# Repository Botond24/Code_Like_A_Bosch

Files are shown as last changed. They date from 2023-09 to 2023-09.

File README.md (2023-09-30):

# Code Like A Bosch Challenge
## Hardware Chalenge
### Ideas
- lapma
- toldo
- nyomatek kijelzo
- Nekem az ötletem a szogmérő, ezt 2 dologra is használhatjuk
    - Egyrészt segíthet kezdőknek hogy jól tartsák a fúrót
    - Másrészt vízszint mérő

### TODO -- Moved to Obsidian/Main doc.md

1. Brainstorm and decide on an idea that can enhance the Bosch 12 screwdriver
    - Business model of your solution
    - Customer need for your extension – how many new customers could be acquired with the new extension
    - Value added for the customer – comfort, safety, efficiency, versatility
    - Feasibility – is this can be really realized?
    - Costs – development, BOM, sale price
2. Overview of the proposed solution – block diagram, infographics, etc.
3. Schematic of the proposed solution – the real connection between the components, modules, can be done in CAD, or in paint.
4. Simulations and calculations of the main component, or part of the hardware (if applicable)
5. Documentation of your idea and solution
6. Firmware block diagram (only if applicable to your idea)
7. Firmware code, or segment of your algorithm (only if applicable to your idea)
8. Explain your idea and introduce your team in a video
9. Optional for additional points: start prototyping and bring your idea to life with the provided tools, hardware components on site (HW + firmware)

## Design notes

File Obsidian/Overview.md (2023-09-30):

```mermaid
graph TD
    phase1["`phase 1
    figuring out what can help people`"] --> phase2["`phase 2
    search for a way to make it low cost`"] --> phase3["`phase 3
    desing the screwdriver inside to make everthing fit`"] --> phase4["`phase 4
    build a prototype and test is it useable`"] --> phase5["`phase 5
    finishing touches to the production version`"]
```

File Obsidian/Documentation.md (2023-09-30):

# Documentation

## System Block Diagram
```mermaid
graph TD
	MCU --> Display
	TOF[Proximity Sensor x4] --> MCU
	12V --> DCDC
	DCDC --> MCU
	DCDC --> TOF
```

## BOM

| Item | Qty | Reference(s) | Value | LibPart | Footprint | Datasheet | DNP | Height | Manufacturer_Name  | Manufacturer_Part_Number | Mouser Part Number | Mouser Price/Stock |
|:-----|:----|:---|:---|:---|:---|:---|:----|:---|:---|:---|:---|:---|
| 2 | 5 | C5, C6, C7, C8, C14 | GRT155R61A475ME13J | GRT155R61A475ME13J:GRT155R61A475ME13J | CAPC1005X55N | https://psearch.en.murata.com/capacitor/product/GRT155R61A475ME13%23.html | | 0.55 | Murata Electronics | GRT155R61A475ME13J | 81-GRT155R61A475ME3J | https://www.mouser.co.uk/ProductDetail/Murata-Electronics/GRT155R61A475ME13J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 |
| 3 | 1 | C11 | C0402C271K5RAC | C0402C271K5RAC:C0402C271K5RAC | CAPC1005X55N | https://content.kemet.com/datasheets/KEM_C1002_X7R_SMD.pdf | | 0.55 | KEMET | C0402C271K5RAC | 80-C0402C271K5RAC | https://www.mouser.co.uk/ProductDetail/KEMET/C0402C271K5RAC?qs=cr8T4Ugre45g%252BE5NGMDJuA%3D%3D |
| 4 | 1 | C12 | GRM188R61C106MA73J | GRM188R61C106MA73J:GRM188R61C106MA73J | CAPC1608X90N | http://componentsearchengine.com/Datasheets/1/GRM188R61C106MA73J.pdf | | 0.9 | Murata Electronics | GRM188R61C106MA73J | 81-GRM188R61C106MA3J | https://www.mouser.co.uk/ProductDetail/Murata-Electronics/GRM188R61C106MA73J?qs=QzBtWTOodeVxskQb7yWr5w%3D%3D |
| 5 | 1 | J1 | Conn_01x04_Pin | Connector:Conn_01x04_Pin | Connector_PinSocket_1.00mm:PinSocket_1x04_P1.00mm_Vertical | ~ | | | | | | |
| 6 | 1 | L1 | SRN2012T-6R8K | SRN2012T-6R8K:SRN2012T-6R8K | INDPM2012X120N | http://www.bourns.com/docs/Product-Datasheets/SRN2012T.pdf | | 1.2 | Bourns | SRN2012T-6R8K | 652-SRN2012T-6R8K | https://www.mouser.co.uk/ProductDetail/Bourns/SRN2012T-6R8K?qs=A6eO%252BMLsxmSuOZAvAVKYXQ%3D%3D |
| 7 | 1 | R1 | 0603WAJ0103T5E | 0603WAJ0103T5E:0603WAJ0103T5E | RESC1608X55N | | | 0.55 | ROYALOHM | 0603WAJ0103T5E | 303-0603WAJ0103T5E | https://www.mouser.co.uk/ProductDetail/Royalohm/0603WAJ0103T5E?qs=e8oIoAS2J1RbD%2Fl9RKhEzg%3D%3D |
| 8 | 1 | U1 | STM32C011J_4-6_Mx  | MCU_ST_STM32C0:STM32C011J_4-6_Mx | Package_SO:SOIC-8_3.9x4.9mm_P1.27mm | https://www.st.com/resource/en/datasheet/stm32c011j4.pdf | | | | | | https://eu.mouser.com/ProductDetail/STMicroelectronics/STM32C011J4M6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|
| 9 | 1 | U2 | ~ | Converter_DCDC:IEB0112S3V3 | Converter_DCDC:IEB01 | | | | | | | |
| 10 | 1 | U3 | ~ | Driver_Display:SSD1306 | Connector_PinSocket_1.00mm:PinSocket_1x04_P1.00mm_Vertical | | | | | | | |
| 11 | 4 | U4, U5, U6, U7 | VL53L0CXV0DH_1 | VL53L0CXV0DH_1:VL53L0CXV0DH_1 | KiCad:LGA12_1 | http://www.st.com/content/ccc/resource/technical/document/datasheet/group3/b2/1e/33/77/c6/92/47/6b/DM00279086/files/DM00279086.pdf/jcr:content/translations/en.DM0027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 | | | STMicroelectronics | VL53L0CXV0DH/1 | 511-VL53L0CXV0DH/1 | https://www.mouser.co.uk/ProductDetail/STMicroelectronics/VL53L0CXV0DH-1?qs=dTJS0cRn7ojtsK3C9%252BTaSw%3D%3D |  

4x2.32 + 1x0.493 + 1x0.001 + 1x0.068 + 1x0.034 + 1x0.05 + 5x0.02 + 1x64.10 + development = 74.126  + development = 89.99 EUR
## Schematic

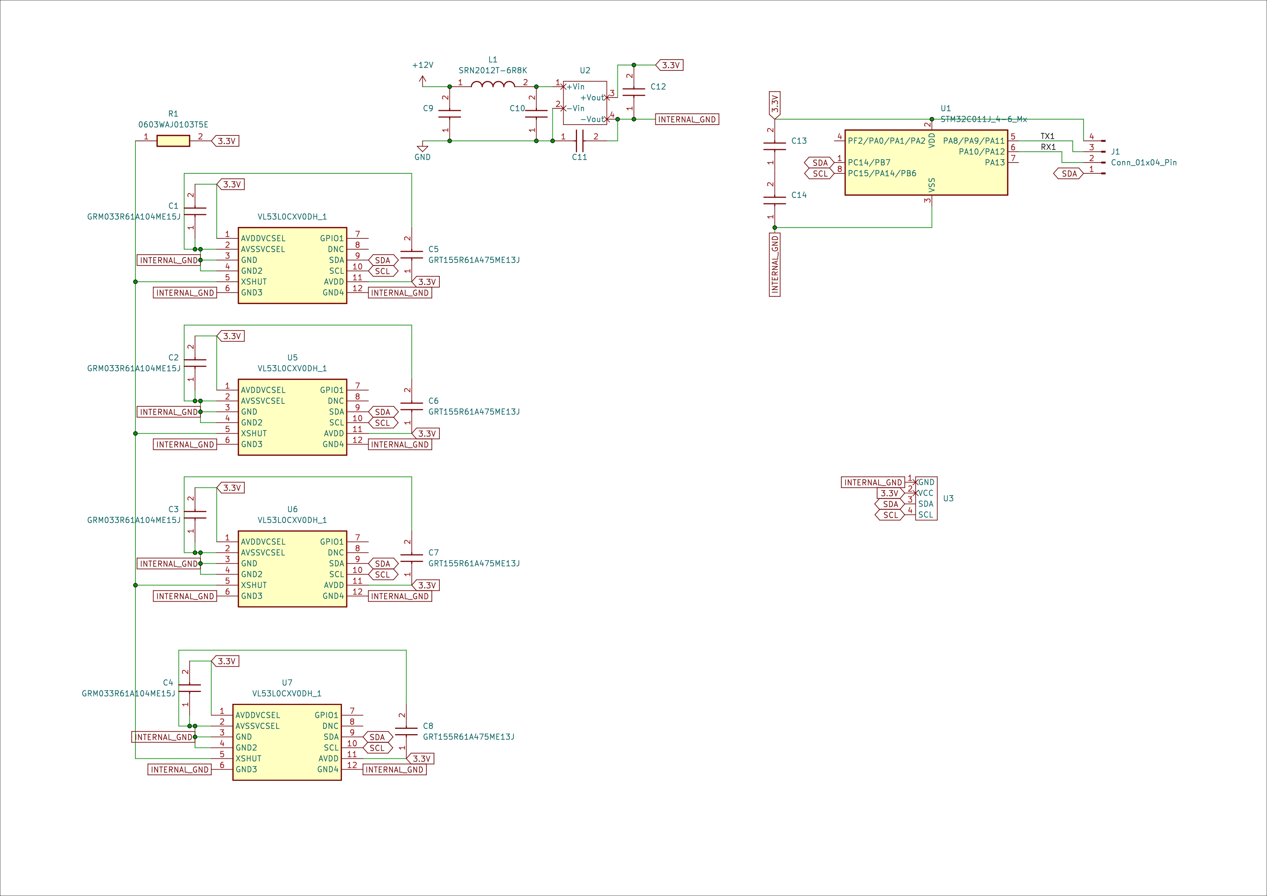
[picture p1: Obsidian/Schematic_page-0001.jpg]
Schematic


## Calculations

We calculated the distance of the head fron the screw, and the angle using only 2 of the sensors.
</br></br>
The formulas we came up with:
$$d_0 = \frac{D_{s1} +d_{s2}}{2}, \alpha = \tan\left(|{d_{s1}-d_s2}|\right)$$

These of course work with any of the opposing sensors to get the anglo of the given axis.

## Working Priciple

With the TOF sensors we get the distance difference, and use that to calculate the angle in the given axis.

The TOF has a range from 5cm to 120cm being more than enough for our purposes.

## Firmware Block Diagram

```mermaid
graph TD
    phase1["`main thread
    check TD and LR sensors 
    difference in absulute 
    value`"] --> phase2["run the calculation to get tha angel"] --> phase3["if the angle is greater than 1 degree"] --> phase4["warn the user that the driver is not straight "] --> phase6["sleep 100ms"] --> phase1
    phase3 --> phase5["else"] --> phase6
```

## Business Model

We ainly focus one beginners and completely stangers to the given tool. Ris way we can bring many new customers, while also providing them and older customers quality features.

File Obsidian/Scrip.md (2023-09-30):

Has this ever happened to you?
Stripped screws?
Messed up drills?

WELL DO WE HAVE A PRODCUT FOR YOU! (yes we do)

Let me introduce you to **AlignBit**!

Our state of the art product has been in development for years. Our innovators worked day and night to develop the product!

Wiht it you no longer have to worry about filling accidental holes, stripping screw heads!
Thanks to our revolutionary idea, even your Grandma could start crafting!
YES YOU HEARD THAT RIGHT, YOUR GRNADMA!

For only 89.99 Euros it could be yours!

But wait, if you buy now
You also get a complimentary carrying case

So Dont hesitate and buy now at www.bosch.com

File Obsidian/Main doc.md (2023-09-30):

1. Brainstorm and [[decide]] on an idea that can enhance the Bosch 12 screwdriver ✅
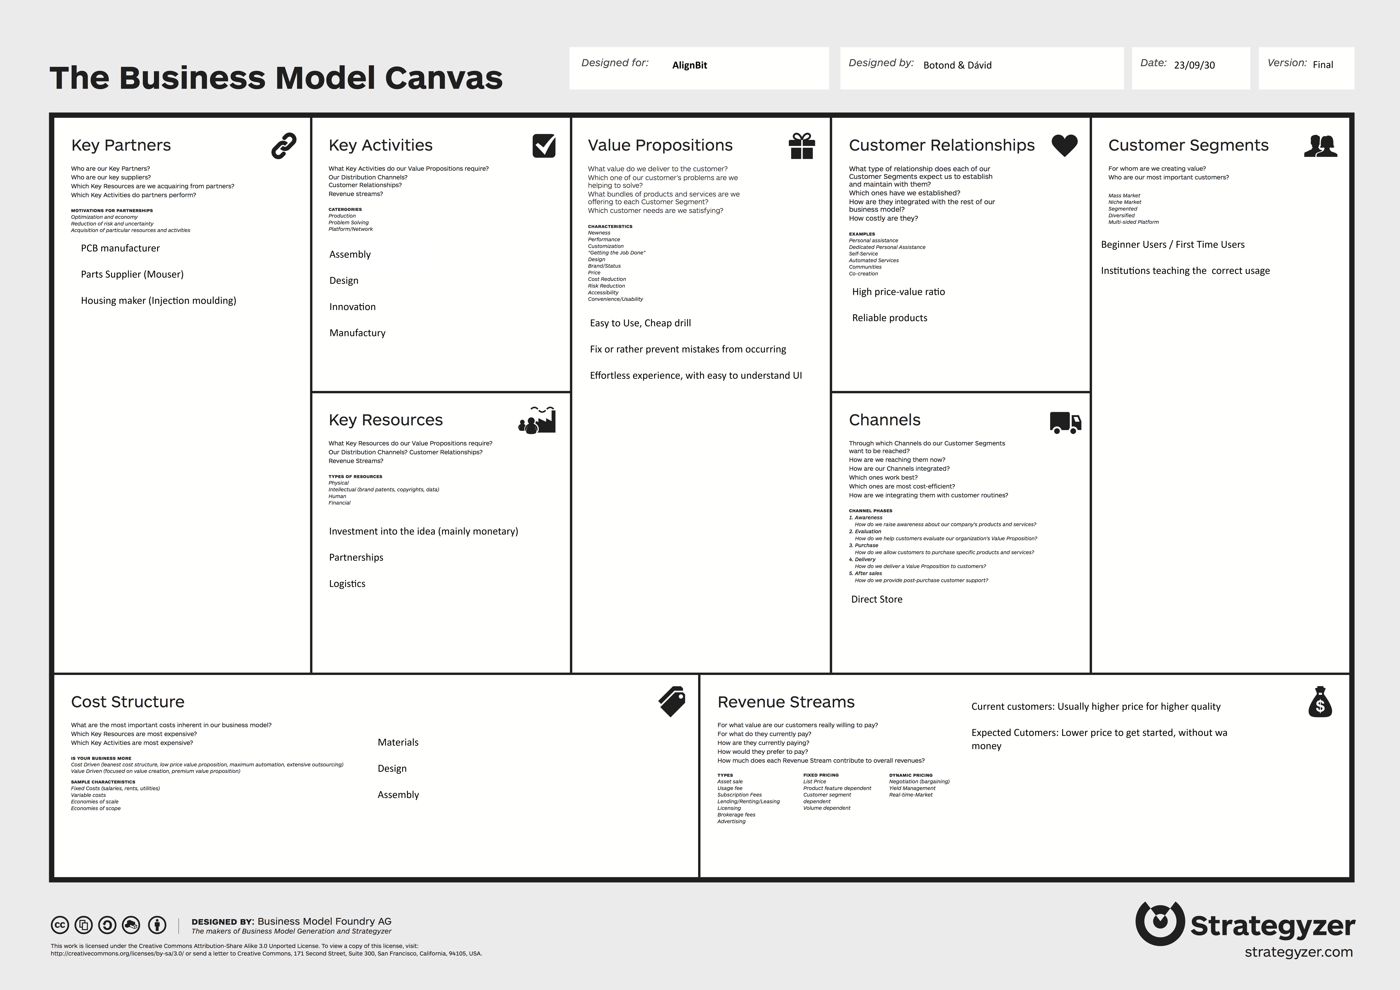
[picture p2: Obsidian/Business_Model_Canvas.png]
Business model
    -  of your solution - Button ✅
    - [[Customer need]] for your extension – how many new customers could be acquired with the new extension - Button ✅
    - [[Value added]] for the customer – comfort, safety, efficiency, versatility ✅
    - [[Feasibility]] – is this can be really realized? ✅
    - [[Costs]] – development, BOM, sale price - Button ✅
2. [[Overview]] of the proposed solution – block diagram, infographics, etc. ✅
3. [[Schematic.pdf|Schematic]] of the proposed solution – the real connection between the components, modules, can be done in CAD, or in paint.  ✅
4. [[Calculations.pdf|Simulations and calculations]] of the main component, or part of the hardware (if applicable) ✅ --- simulations important
5. [[Documentation]] of your idea and solution
6. [[Firmware]] block diagram (only if applicable to your idea) ✅
7. Firmware code, or segment of your algorithm (only if applicable to your idea) ✅
8. Explain your idea and introduce your team in a [[video]] -- Pl.: Advertisement --ppt -- paints
9. **Optional for additional points**: start prototyping and bring your idea to life with the provided tools, hardware components on site (HW + firmware)

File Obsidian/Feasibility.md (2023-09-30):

While designing the device we consider the amount of space available making sure to stay inside it.

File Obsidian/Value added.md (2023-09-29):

- Makes easier for beginners to hod the drill at the perfect angle
- Helps you bite less screwheads
- Doesn't makes it noticeably heavier

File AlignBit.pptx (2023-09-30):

## AlignBit

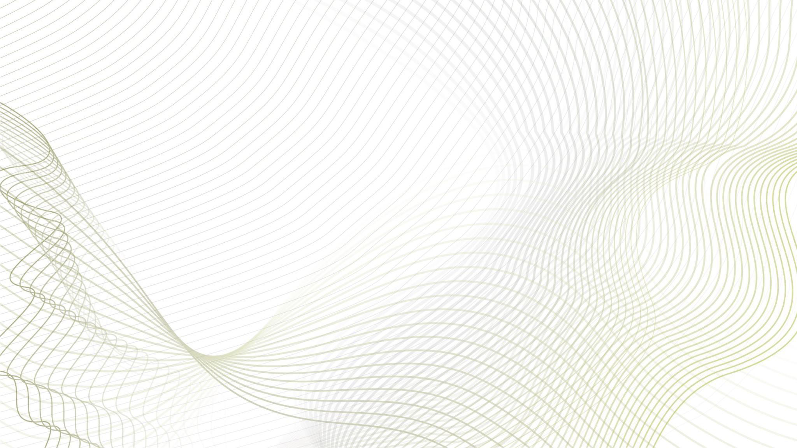
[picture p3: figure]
A képen vázlat, fehér, szövet, művészet látható Automatikusan generált leírás

By Sebe Dávid and Szihalmi Botond Béla

## Main Idea

Our main idea came from personal experience. Both of us have had the pleasure to strip some screws while working on a project, and not be able to unscrew them.
After some Brainstorming we produced the idea to help other with this exact problem.

## Implementation

Our first job was to figure how we could realise this.
Of course, the most obvious answer is to use a gyroscope. The problem with it is even if we calibrate the gyroscope on button press, we cannot trust the user to hold the drill at the correct angle while we calibrate.
So, we switched to using 4 TOF (Time-Of-Flight) sensors arranged in a “plus” so we could measure 2 degrees of freedom (Pitch, Yaw).

## Why is it important?

It helps get started to the new peoples and basically everyone could use it.
It helps not to make mistakes more often and able to make it faster

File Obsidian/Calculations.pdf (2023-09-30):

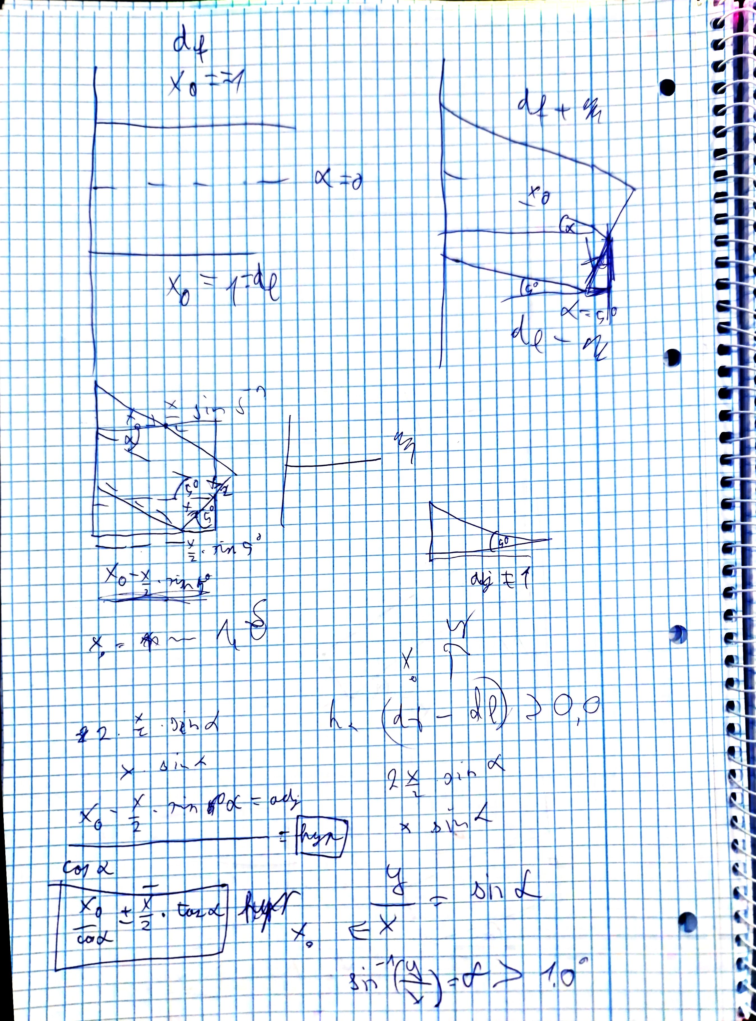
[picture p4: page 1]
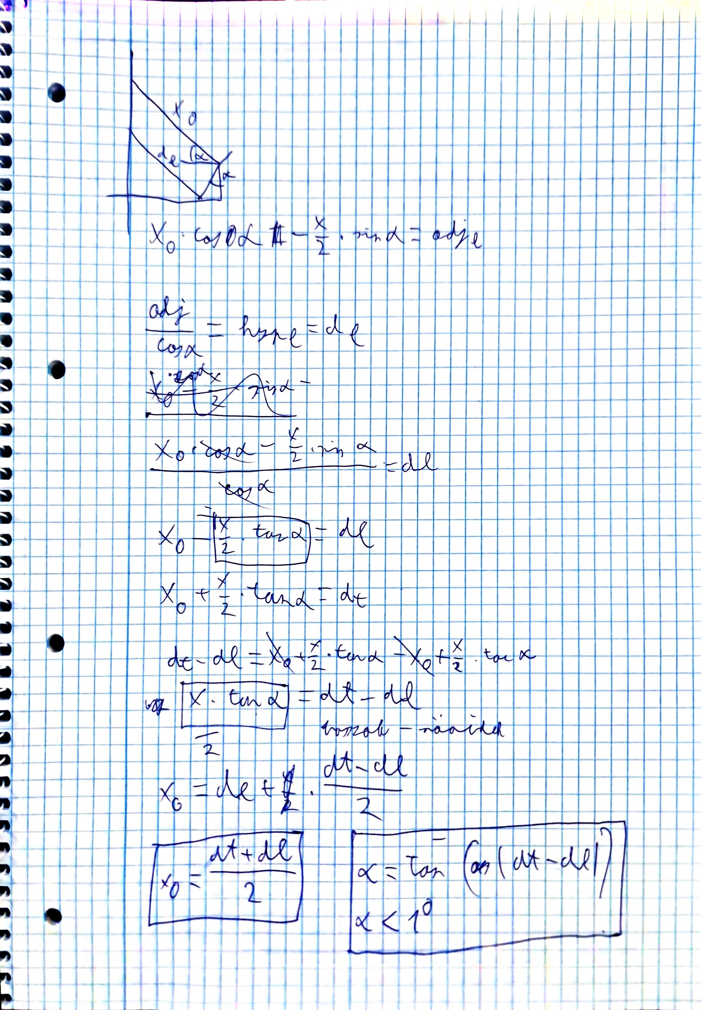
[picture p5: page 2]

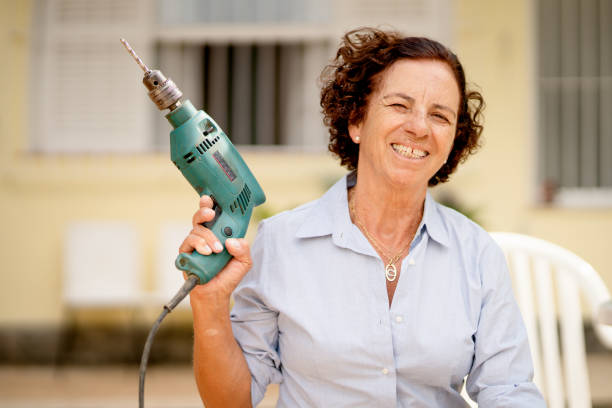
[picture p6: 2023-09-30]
video/smiling-mature-woman-holding-a-drill-while-doing-some-diy-at-home.png

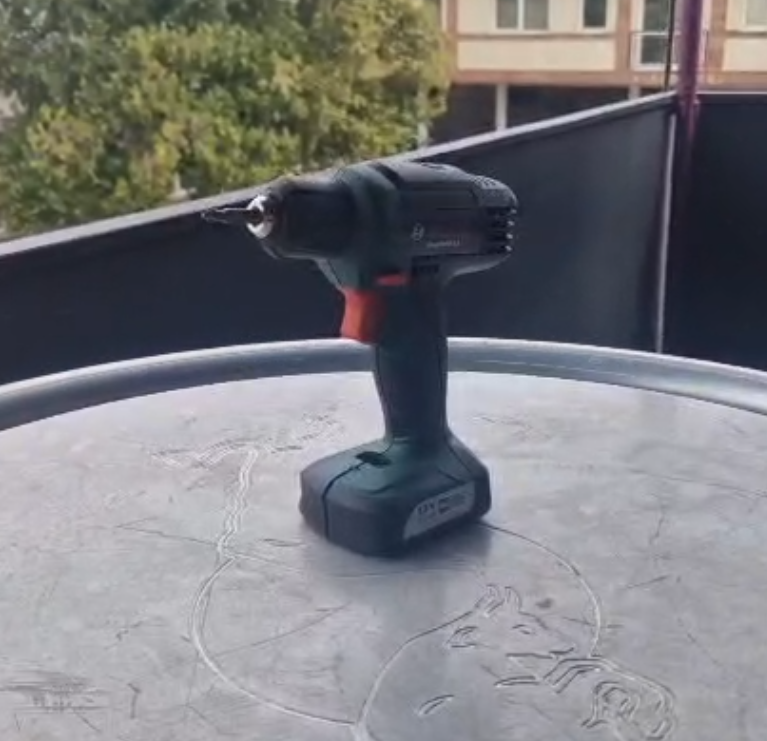
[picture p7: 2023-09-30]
video/the drill.png

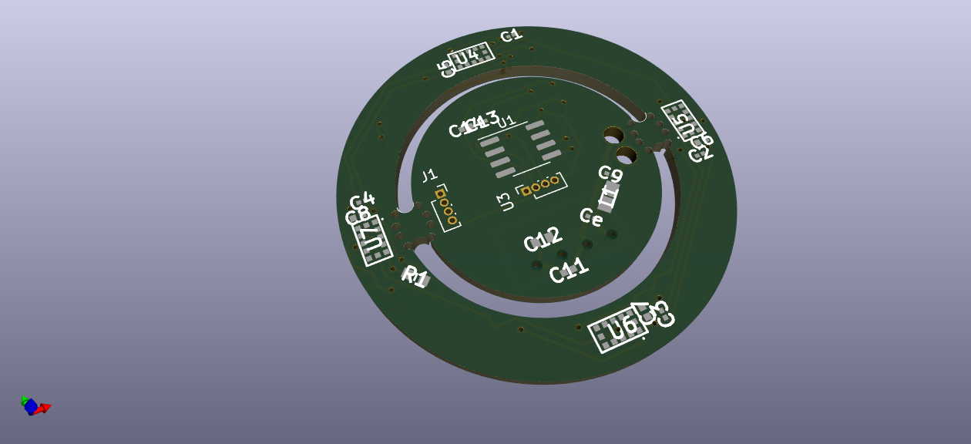
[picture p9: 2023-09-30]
Obsidian/PCB.png

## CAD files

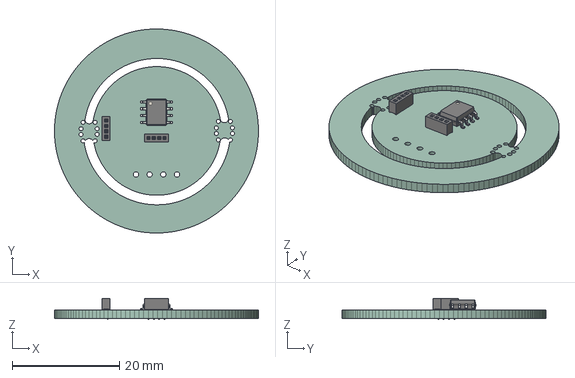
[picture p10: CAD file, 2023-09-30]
AlignBit/AlignBit.step
38.0 x 38.0 x 4.00 mm
AlignBit PCB

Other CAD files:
AlignBit/AlignBit PCB.ipt
AlignBit/OldVersions/AlignBit PCB.0001.ipt

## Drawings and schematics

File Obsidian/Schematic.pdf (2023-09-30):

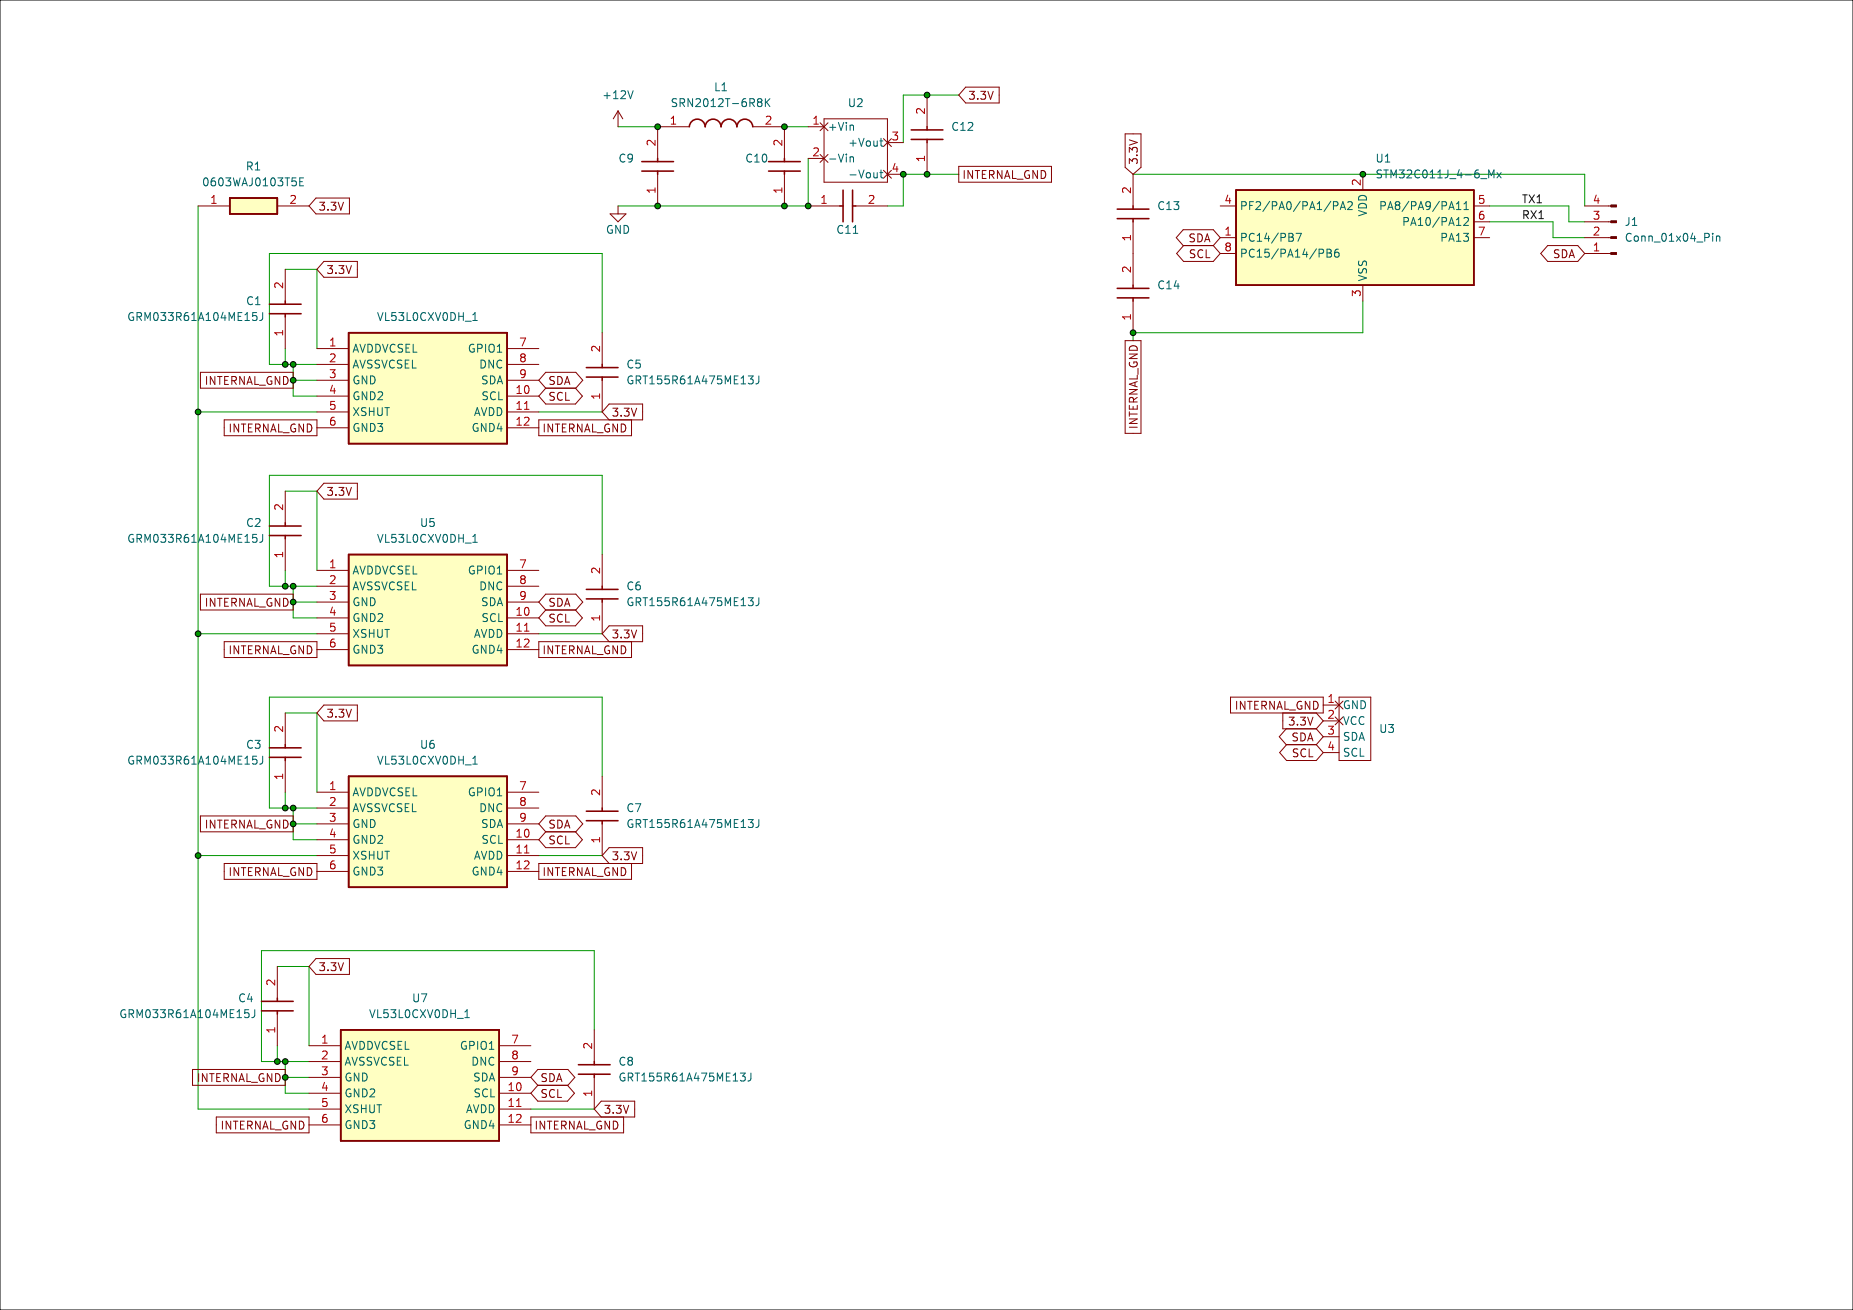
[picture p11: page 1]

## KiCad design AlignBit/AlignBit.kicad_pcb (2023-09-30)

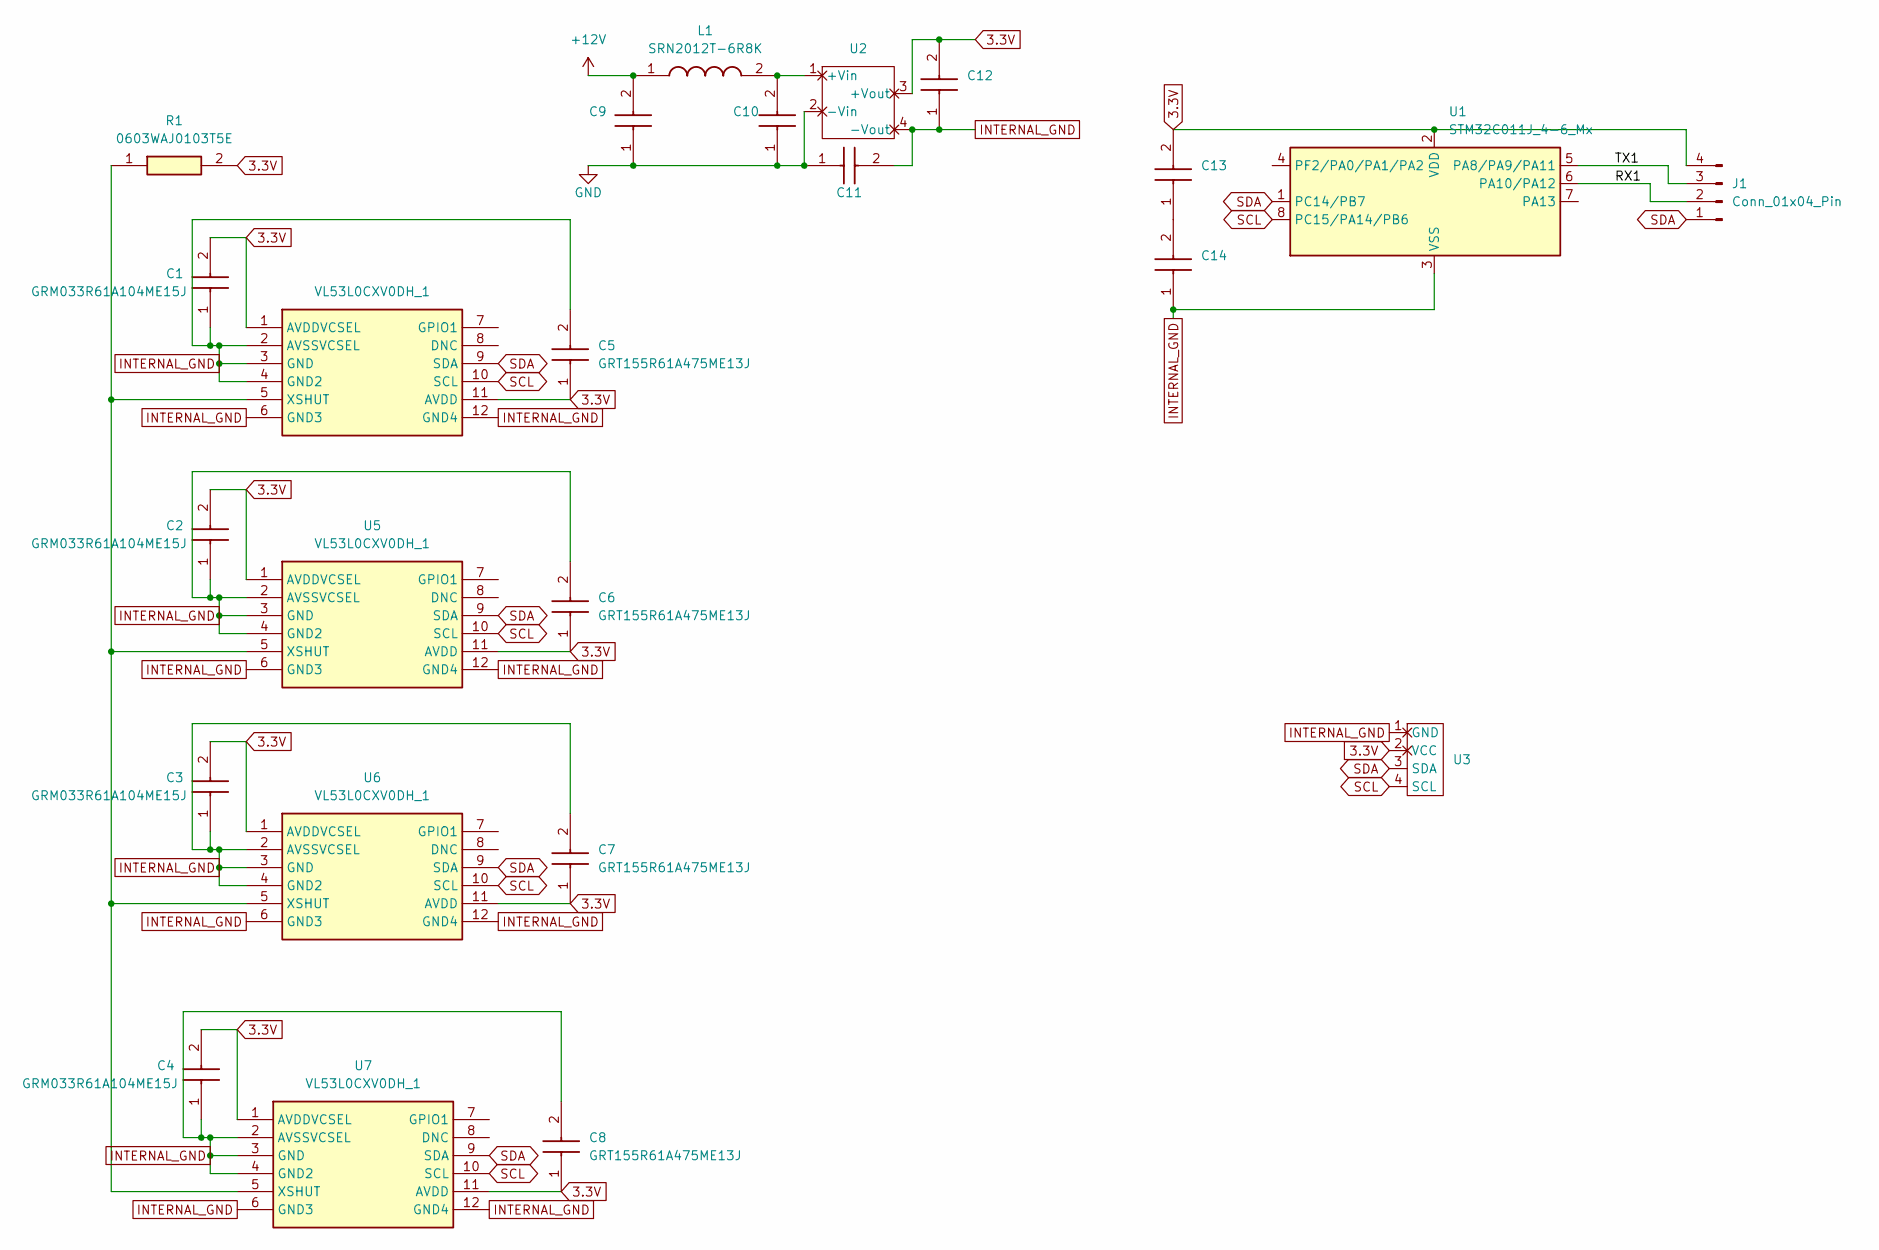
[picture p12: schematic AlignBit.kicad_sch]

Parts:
C1, C2, C3, C4, C9, C10, C13: GRM033R61A104ME15J; CAPC0603X33N; Mouser Part Number 81-GRM033R61A104ME5J
C5, C6, C7, C8, C14: GRT155R61A475ME13J; CAPC1005X55N; Mouser Part Number 81-GRT155R61A475ME3J
C11: C0402C271K5RAC; CAPC1005X55N; Mouser Part Number 80-C0402C271K5RAC
C12: GRM188R61C106MA73J; CAPC1608X90N; Mouser Part Number 81-GRM188R61C106MA3J
J1: Conn_01x04_Pin; PinSocket_1x04_P1.00mm_Vertical
L1: SRN2012T-6R8K; INDPM2012X120N; Mouser Part Number 652-SRN2012T-6R8K
R1: 0603WAJ0103T5E; RESC1608X55N; Mouser Part Number 303-0603WAJ0103T5E
U1: STM32C011J_4-6_Mx; SOIC-8_3.9x4.9mm_P1.27mm
U2: IEB01
U3: PinSocket_1x04_P1.00mm_Vertical
U4, U5, U6, U7: VL53L0CXV0DH_1; LGA12_1; Mouser Part Number 511-VL53L0CXV0DH/1

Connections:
3.3V: C1.2, C2.2, C3.2, C4.2, C5.1, C6.1, C7.1, C8.1, C12.2, C13.2, J1.4, R1.2, U1.2 (VDD), U2.3 (+Vout), U3.2 (VCC), U4.1 (AVDDVCSEL), U4.11 (AVDD), U5.1 (AVDDVCSEL), U5.11 (AVDD), U6.1 (AVDDVCSEL), U6.11 (AVDD), U7.1 (AVDDVCSEL), U7.11 (AVDD)
+12V: C9.2, L1.1
/RX1: J1.2, U1.6 (PA10/PA12)
/TX1: J1.3, U1.5 (PA8/PA9/PA11)
GND: C9.1, C10.1, C11.1, U2.2 (-Vin); also elsewhere on the board
INTERNAL_GND: C1.1, C2.1, C3.1, C4.1, C5.2, C6.2, C7.2, C8.2, C11.2, C12.1, C14.1, U1.3 (VSS), U2.4 (-Vout), U3.1 (GND), U4.2 (AVSSVCSEL), U4.3 (GND), U4.4 (GND2), U4.6 (GND3), U4.12 (GND4), U5.2 (AVSSVCSEL), U5.3 (GND), U5.4 (GND2), U5.6 (GND3), U5.12 (GND4), U6.2 (AVSSVCSEL), U6.3 (GND), U6.4 (GND2), U6.6 (GND3), U6.12 (GND4), U7.2 (AVSSVCSEL), U7.3 (GND), U7.4 (GND2), U7.6 (GND3), U7.12 (GND4)
unnamed: C13.1, C14.2
unnamed 7: C10.2, L1.2, U2.1 (+Vin); also elsewhere on the board
unnamed: R1.1, U4.5 (XSHUT), U5.5 (XSHUT), U6.5 (XSHUT), U7.5 (XSHUT)
SCL: U1.8 (PC15/PA14/PB6), U3.4 (SCL), U4.10 (SCL), U5.10 (SCL), U6.10 (SCL), U7.10 (SCL)
SDA: J1.1, U1.1 (PC14/PB7), U3.3 (SDA), U4.9 (SDA), U5.9 (SDA), U6.9 (SDA), U7.9 (SDA)

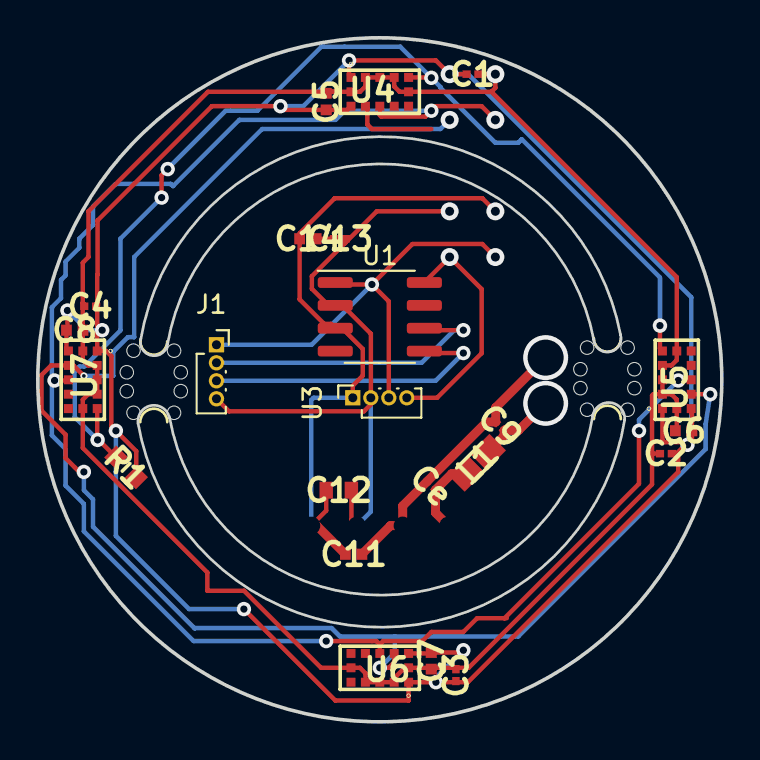
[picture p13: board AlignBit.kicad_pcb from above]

Board: 2 copper layers, 38.0 x 38.0 mm, 26 parts (1 on the bottom side), 11 nets.

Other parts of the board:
Ce: GRM033R61A104ME15J; CAPC0603X33N
mouse-bite-1.5mm-slot, mouse-bite-1.5mm-slot#2: VAL**; mouse-bite-1.5mm-slot

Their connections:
GND: Ce.1; also elsewhere on the board
unnamed 7: Ce.2; also elsewhere on the board

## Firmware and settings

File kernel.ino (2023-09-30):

/* This example shows how to use continuous mode to take
range measurements with the VL53L0X. It is based on
vl53l0x_ContinuousRanging_Example.c from the VL53L0X API.

The range readings are in units of mm. */

#include <Wire.h>
#include <VL53L0X.h>
#include <math.h>

VL53L0X sensorT;
VL53L0X sensorL;
VL53L0X sensorR;
VL53L0X sensorD;

void setup()
{
  Serial.begin(9600);
  Wire.begin();

  sensorT.setTimeout(500);
  if (!sensorT.init())
  {
    Serial.println("Failed to detect and initialize sensorT!");
    while (1) {}
  }
  sensorR.setTimeout(500);
  if (!sensorR.init())
  {
    Serial.println("Failed to detect and initialize sensorR!");
    while (1) {}
  }
  sensorD.setTimeout(500);
  if (!sensorD.init())
  {
    Serial.println("Failed to detect and initialize sensorD!");
    while (1) {}
  }
  sensorL.setTimeout(500);
  if (!sensorL.init())
  {
    Serial.println("Failed to detect and initialize sensorL!");
    while (1) {}
  }

  // Start continuous back-to-back mode (take readings as
  // fast as possible).  To use continuous timed mode
  // instead, provide a desired inter-measurement period in
  // ms (e.g. sensor.startContinuous(100)).
  sensorT.setAddress(0xE0);
  sensorR.setAddress(0xE3);
  sensorD.setAddress(0xE2);
  sensorL.setAddress(0xE1);
  sensorT.startContinuous();
  sensorR.startContinuous();
  sensorD.startContinuous();
  sensorL.startContinuous();
}

void loop()
{
  if (atan(abs(sensorT.readRangeContinuousMillimeters() - sensorD.readRangeContinuousMillimeters())) > 1.0)
    //alert the user
  if (atan(abs(sensorL.readRangeContinuousMillimeters() - sensorR.readRangeContinuousMillimeters())) > 1.0)
    //alert the user
}

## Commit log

2023-09-29 Strated Schematic
    [Fancy_Name.kicad_pcb, Fancy_Name.kicad_sch]
2023-09-30 Lots finished
    Final name
    Schematic
    PCB
    Business model
    Cost
    [AlignBit.kicad_pcb, AlignBit.kicad_sch, Fancy_Name.kicad_pcb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]
2023-09-30 Adding things untill its done
    [AlignBit.kicad_pcb, AlignBit.kicad_sch]
2023-09-30 Bom is the only left
2023-09-30 adding ppt
    [AlignBit PCB.0001.ipt, AlignBit PCB.ipt, AlignBit.kicad_pcb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]
